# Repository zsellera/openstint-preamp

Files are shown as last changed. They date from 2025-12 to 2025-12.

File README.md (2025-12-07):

# OpenStint Loop Preamplifier Board

The **OpenStint Loop Preamplifier Board** is an optional front-end module, designed for the [OpenStint Laptimer System](https://github.com/zsellera/openstint). It provides signal conditioning and amplification for the parallel-wire "antenna", ensuring clean, stable, and maximized signal transfer to the timing receiver.

openstint preamp, rev 1.

## 🔧 Features

- Fully compatible with the OpenStint timing receiver interface. Operated from the bias-tee available on HackRF One and RTLSDR.
- Output is matched to 50 Ohm.
- +12 dB gain low-noise amplifier
- Fits Hammond's 1590L-style aluminium cases
- Power pin available for 1S batteries (remove `L6` or `FB2` in this case, or add DC-block capacitor before the SDR).
- Open hardware design – schematics and PCB available under permissive license
- Directly manufacturable at JLCPCB (LCSC part codes provided).

## ✳️ Measurement Results

The following measurements were made at the `VNA_IN` port (after the balun).

**POWER GAIN**


**INPUT MATCHING**


## Schematics


## 🗺 Roadmap / Project ideas

Add an optional 75 Ohm output as well, or add a separate 50 to 50+75 splitter. This hardware change should have a software counterpart, which reads both the OpenStint and MyLaps decoders, and merges the results into a single stream for laptiming applications. We could keep both open and commercial transponders to co-exists on the same track this way. Also, upgrading post-4.4 firmware won't be such a headache neither.

Automatic gain control: even a simple one could increase the dynamic range of the decoders.

---
Part of the OpenStint Laptimer System – open, modular, and precise RC timing.

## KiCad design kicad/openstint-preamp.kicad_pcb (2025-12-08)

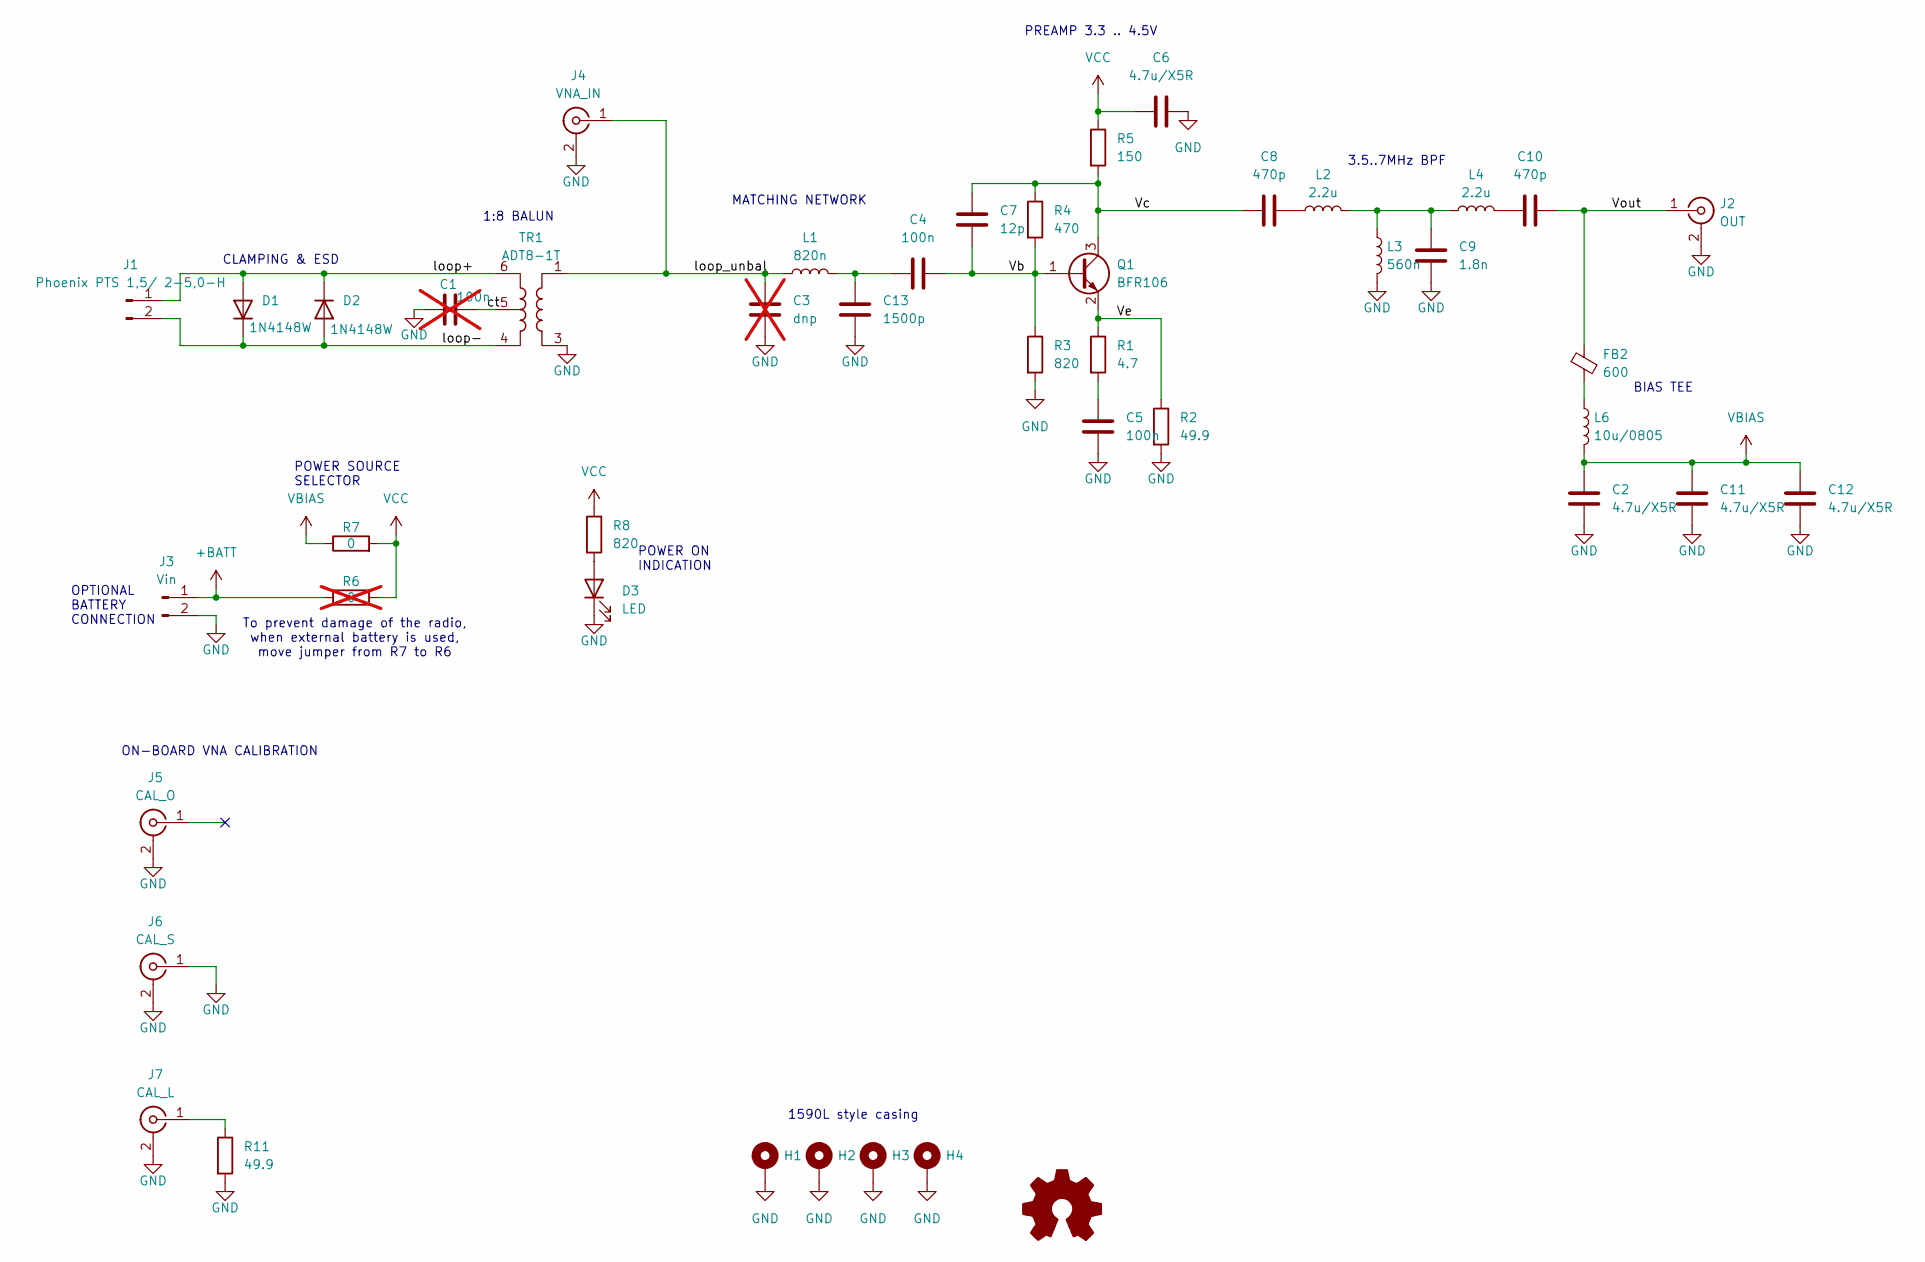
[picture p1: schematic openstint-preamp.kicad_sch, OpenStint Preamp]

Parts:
C1: 100n; C_0603_1608Metric; LCSC C14663; not fitted
C2, C6, C11, C12: 4.7u/X5R; C_0603_1608Metric; LCSC C19666
C3: dnp; C_0603_1608Metric; not fitted
C4, C5: 100n; C_0603_1608Metric; LCSC C14663
C7: 12p; C_0603_1608Metric; LCSC C38523
C8, C10: 470p; C_0603_1608Metric; LCSC C1620
C9: 1.8n; C_0603_1608Metric; LCSC C107042
C13: 1500p; C_0603_1608Metric; LCSC C1595
D1, D2: 1N4148W; D_SOD-123F; LCSC C81598
D3: LED; LED_1206_3216Metric_ReverseMount_Hole1.8x2.4mm; mouser 710-156120VS75000
FB2: 600; L_0805_2012Metric; LCSC C1017
H1, H2, H3, H4: MountingHole_Pad; MountingHole_4.3mm_M4_DIN965_Pad
J1: Phoenix PTS 1,5/ 2-5,0-H; TerminalBlock_Phoenix_PT-1,5-2-5.0-H_1x02_P5.00mm_Horizontal; mouser 651-1792863
J2: OUT; SMA_Amphenol_132134-16_Vertical
J3: Vin; JST_PH_B2B-PH-K_1x02_P2.00mm_Vertical; LCSC C131337
J4: VNA_IN; U.FL_Hirose_U.FL-R-SMT-1_Vertical; LCSC C5137195
J5: CAL_O; U.FL_Hirose_U.FL-R-SMT-1_Vertical; LCSC C5137195
J6: CAL_S; U.FL_Hirose_U.FL-R-SMT-1_Vertical; LCSC C5137195
J7: CAL_L; U.FL_Hirose_U.FL-R-SMT-1_Vertical; LCSC C5137195
L1: 820n; L_0603_1608Metric; LCSC C18213078
L2, L4: 2.2u; L_0603_1608Metric; LCSC C337910
L3: 560n; L_0603_1608Metric; LCSC C114773
L6: 10u/0805; L_0805_2012Metric; LCSC C88173
Q1: BFR106; SOT-23; LCSC C439780
R1: 4.7; R_0603_1608Metric; LCSC C23164
R2, R11: 49.9; R_0603_1608Metric; LCSC C23185
R3, R8: 820; R_0603_1608Metric; LCSC C23253
R4: 470; R_0603_1608Metric; LCSC C23179
R5: 150; R_0603_1608Metric; LCSC C22808
R6: 0; R_0603_1608Metric; LCSC C21189; not fitted
R7: 0; R_0603_1608Metric; LCSC C21189
SYM1: Logo_Open_Hardware_Small; OSHW-Logo2_9.8x8mm_SilkScreen
TR1: ADT8-1T; Mini-Circuits_CD637_H5.23mm

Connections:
+BATT: J3.1, R6.1
/Vb: C4.2, C7.1, Q1.1 (B), R3.1, R4.2
/Vc: C7.2, C8.1, Q1.3 (C), R4.1, R5.2
/Ve: Q1.2 (E), R1.1, R2.1
/Vout: C10.2, FB2.1, J2.1 (In)
/ct: C1.2, TR1.5
/loop+: D1.2 (A), D2.1 (K), J1.1, TR1.6
/loop-: D1.1 (K), D2.2 (A), J1.2, TR1.4
/loop_unbal: C3.1, J4.1 (In), L1.1, TR1.1
GND: C1.1, C2.1, C3.2, C5.2, C6.2, C9.2, C11.1, C12.1, C13.2, D3.1 (K), H1.1, H2.1, H3.1, H4.1, J2.2 (Ext), J3.2, J4.2 (Ext), J5.2 (Ext), J6.1 (In), J6.2 (Ext), J7.2 (Ext), L3.2, R2.2, R3.2, R11.2, TR1.3
unnamed: C5.1, R1.2
unnamed: C8.2, L2.1
unnamed: C9.1, L2.2, L3.1, L4.1
unnamed: C10.1, L4.2
unnamed: C4.1, C13.1, L1.2
unnamed: D3.2 (A), R8.2
unnamed: FB2.2, L6.1
unnamed: J7.1 (In), R11.1
VBIAS: C2.2, C11.2, C12.2, L6.2, R7.1
VCC: C6.1, R5.1, R6.2, R7.2, R8.1

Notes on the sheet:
POWER ON INDICATION
MATCHING NETWORK
OPTIONAL BATTERY CONNECTION
BIAS TEE
1590L style casing
ON-BOARD VNA CALIBRATION
PREAMP 3.3 .. 4.5V
1:8 BALUN
POWER SOURCE SELECTOR
CLAMPING & ESD
To prevent damage of the radio, when external battery is used, move jumper from R7 to R6
3.5..7MHz BPF

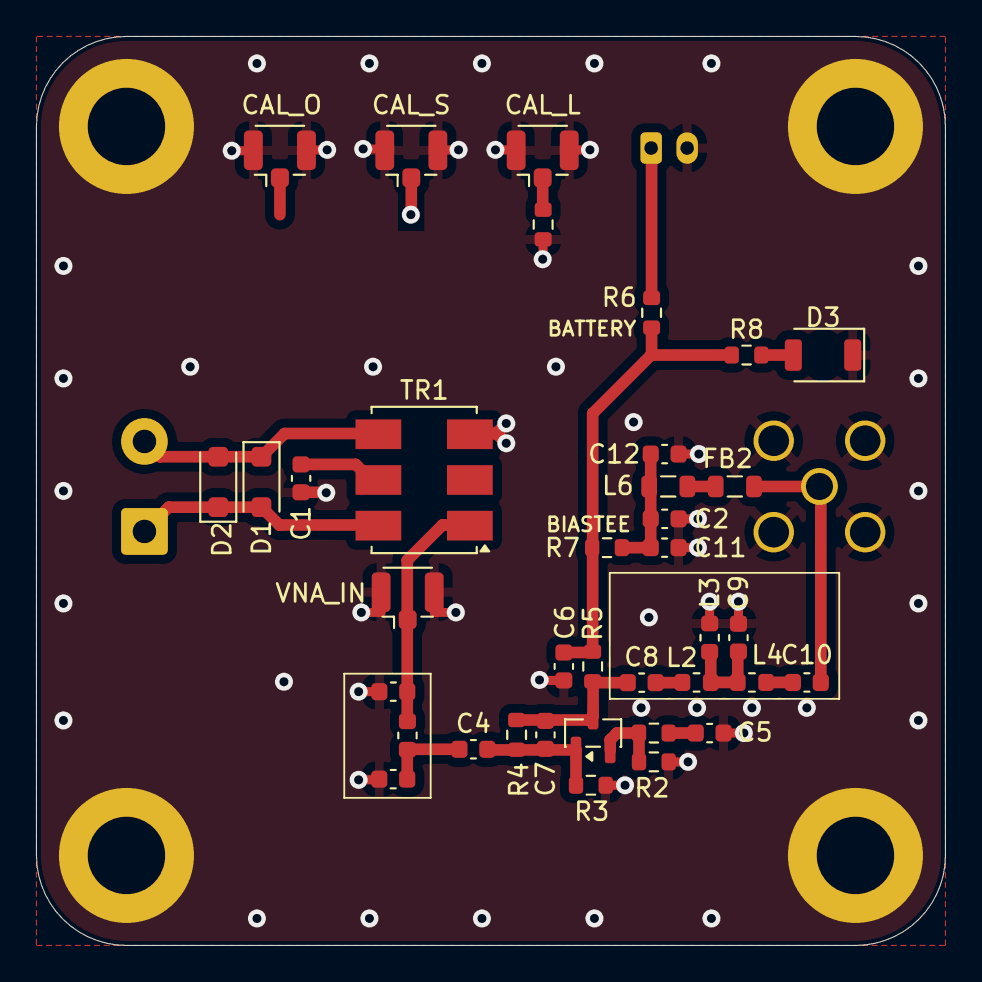
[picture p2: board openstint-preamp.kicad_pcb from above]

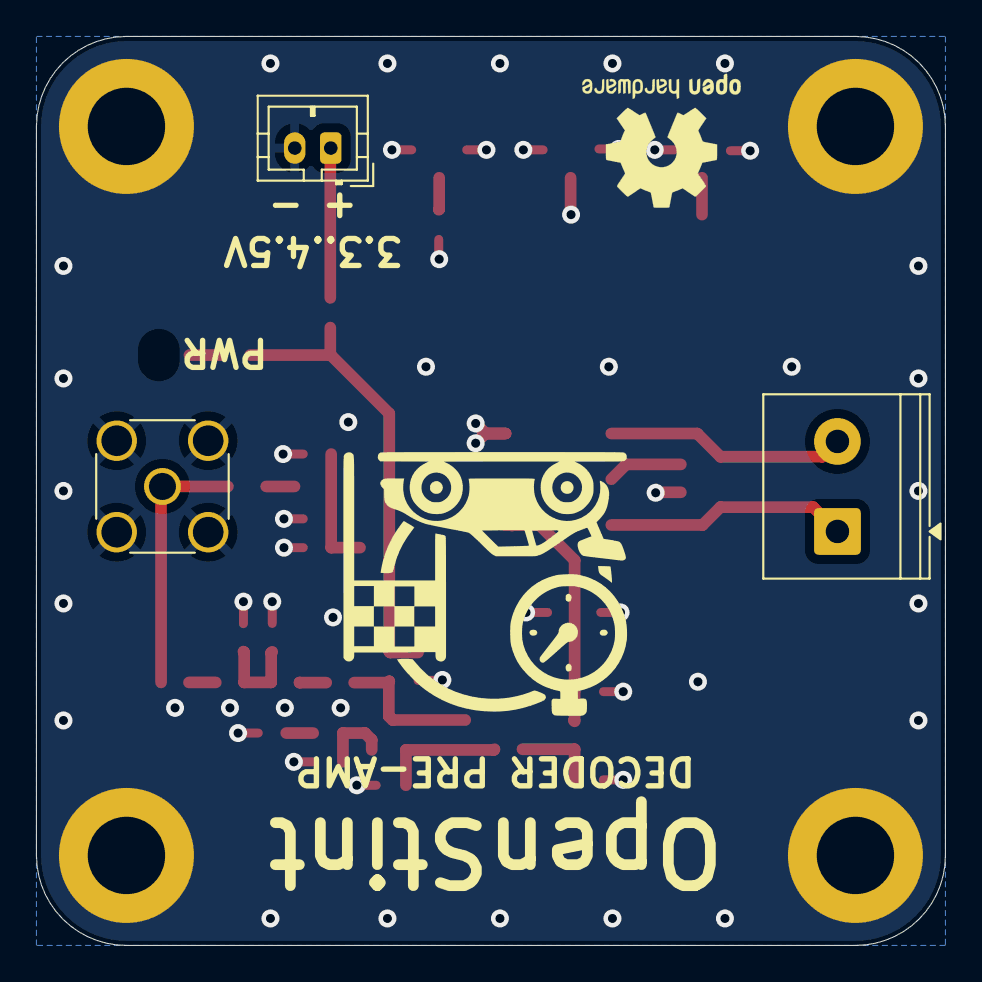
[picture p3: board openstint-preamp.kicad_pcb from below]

Board: 2 copper layers, 50.5 x 50.5 mm, 45 parts (4 on the bottom side), 20 nets.

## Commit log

2025-11-07 Fix GitHub link and add schematics section
    Updated the GitHub link in the README and added a schematics section with an image.
2025-12-08 matching network, battery connection, oshw logo
    [openstint-preamp.kicad_pcb, openstint-preamp.kicad_sch]
